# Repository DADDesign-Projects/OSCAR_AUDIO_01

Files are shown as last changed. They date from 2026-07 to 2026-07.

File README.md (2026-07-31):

# OSCAR Audio Board - OSCAR_AUDIO_01






## 📋 Description

Dedicated electronic board implementing the audio section of the OSCAR effects pedal (https://github.com/DADDesign-Projects/OSCAR_P01A01). This board handles all digital and analog audio processing required for the pedal's operation.

## 🚀 Evolutions

### V2
- Modification of the output summing stage to restore phase alignment identical to the input signal

### V2.1 (PCB V2.2)
- Addition of a second relay to enable true hardware bypass

## 🛠️ Technical Specifications

### Audio Codec
- **PCM3060**: 24-bit stereo audio codec
- **ADC**: 2-channel, 24-bit resolution
- **DAC**: 2-channel, 24-bit resolution
- **Sampling Rate**: Up to 96 kHz

### Analog Dry Channel
- **PGA2310/PGA2311**: Stereo volume controller
- **Analog dry path** for unaffected signal
- **Independent wet/dry mix control**

### Power Supply
- **Isolated Power**: Separate analog and digital domains
- **Input Voltage**: 12V DC
- **Low Noise Regulation**: Multiple LDO regulators
- **Consumption**: < 150mA

## 🛠️ Design Tools
This project was entirely designed using **KiCad 10.0**, the open-source electronics design.

## 📜 License
This project is licensed under the **Apache License 2.0**.

# 📬 Contact
Feel free to contact me for any questions, feedback, improvement suggestions, or collaboration proposals related to the FORGE framework or the OSCAR hardware platform.
I am always open to discussion and community contributions (daddesign.projects@gmail.com).

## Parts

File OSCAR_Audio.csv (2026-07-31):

Reference | Value | Footprint | Datasheet | Qty | DNP | Exclude from BOM | Exclude from Board
C1,C10 | 330p NPO | Capacitor_SMD:C_0805_2012Metric_Pad1.18x1.45mm_HandSolder |  | 2
C2,C9 | 220n | Capacitor_SMD:C_1206_3216Metric_Pad1.33x1.80mm_HandSolder |  | 2
C3,C8,C15,C19 | 10u X7R | Capacitor_SMD:C_1206_3216Metric_Pad1.33x1.80mm_HandSolder |  | 4
C4,C5,C11,C12 | 100p | Capacitor_SMD:C_1206_3216Metric_Pad1.33x1.80mm_HandSolder |  | 4
C6,C21,C22,C23,C24,C25,C26,C33,C35,C40,C42,C43,C45 | 100n | Capacitor_SMD:C_0805_2012Metric_Pad1.18x1.45mm_HandSolder |  | 13
C7,C41,C44 | 10u tal | Capacitor_Tantalum_SMD:CP_EIA-3528-21_Kemet-B_HandSolder |  | 3
C13,C16,C17,C20 | 470p NPO | Capacitor_SMD:C_0805_2012Metric_Pad1.18x1.45mm_HandSolder |  | 4
C14,C18 | 1.5n | Capacitor_SMD:C_0805_2012Metric_Pad1.18x1.45mm_HandSolder |  | 2
C27,C30,C38 | 100u | @Projet:CP_Elec_6.3x9.9_WM |  | 3
C28,C31,C37 | 20u | @Projet:CP_Elec_5x5.4_WM |  | 3
C29,C32,C34,C36 | 10u Tal | Capacitor_Tantalum_SMD:CP_EIA-3528-21_Kemet-B_HandSolder |  | 4
D1,D2 | 1N4148W | Diode_SMD:D_SOD-123 | https://www.vishay.com/docs/85748/1n4148w.pdf | 2
FB1,FB3 | FerriteBead | Inductor_SMD:L_1206_3216Metric_Pad1.22x1.90mm_HandSolder |  | 2
FB2,FB4 | FerriteBead_Small | Inductor_SMD:L_0805_2012Metric_Pad1.05x1.20mm_HandSolder |  | 2
J1 | InL | @Projet:Jack 6.25 | https://www.neutrik.com/en/product/nmj6hcd3 | 1
J2 | InR | @Projet:Jack 6.25 | https://www.neutrik.com/en/product/nmj6hcd3 | 1
J3 | OutR | @Projet:Jack 6.25 | https://www.neutrik.com/en/product/nmj6hcd3 | 1
J4 | OutL | @Projet:Jack 6.25 | https://www.neutrik.com/en/product/nmj6hcd3 | 1
J5 | SAI | Connector_PinHeader_2.54mm:PinHeader_1x07_P2.54mm_Vertical |  | 1
J6 | Vol | Connector_PinHeader_2.54mm:PinHeader_1x06_P2.54mm_Vertical |  | 1
J7,J8 | +12V | Connector_PinHeader_2.54mm:PinHeader_1x02_P2.54mm_Vertical |  | 2
J9 | ByPass | Connector_PinHeader_2.54mm:PinHeader_1x02_P2.54mm_Vertical |  | 1
K1,K2 | G6K-2F-Y | Relay_SMD:Relay_DPDT_Omron_G6K-2F-Y | http://omronfs.omron.com/en_US/ecb/products/pdf/en-g6k.pdf | 2
PS1 | A1209S 2W | @Projet:Converter_DCDC_TRACO_TBA2-xxxx_Dual_THT |  | 1
PS2 | B1209S | @Projet:Converter_DCDC_TRACO_TBA2-xxxx_Single_THT |  | 1
R1,R2,R10,R11,R17,R21,R28,R32,R40,R41,R42,R43,R44 | 10k | Resistor_SMD:R_1206_3216Metric_Pad1.30x1.75mm_HandSolder |  | 13
R3,R9 | 20k | Resistor_SMD:R_1206_3216Metric_Pad1.30x1.75mm_HandSolder |  | 2
R4,R6,R7,R8,R13,R14,R36,R51 | 1k | Resistor_SMD:R_1206_3216Metric_Pad1.30x1.75mm_HandSolder |  | 8
R5,R12,R37 | 220k | Resistor_SMD:R_1206_3216Metric_Pad1.30x1.75mm_HandSolder |  | 3
R15,R23,R26,R35 | 7.5k | Resistor_SMD:R_1206_3216Metric_Pad1.30x1.75mm_HandSolder |  | 4
R16,R20,R27,R31 | 820 | Resistor_SMD:R_1206_3216Metric_Pad1.30x1.75mm_HandSolder |  | 4
R18,R29 | 100 | Resistor_SMD:R_1206_3216Metric_Pad1.30x1.75mm_HandSolder |  | 2
R19,R22,R30,R33 | 22k | Resistor_SMD:R_1206_3216Metric_Pad1.30x1.75mm_HandSolder |  | 4
R24,R34 | 100k | Resistor_SMD:R_1206_3216Metric_Pad1.30x1.75mm_HandSolder |  | 2
R25,R52 | 1K | Resistor_SMD:R_1206_3216Metric_Pad1.30x1.75mm_HandSolder |  | 2
R38,R39 | 4.7k | Resistor_SMD:R_1206_3216Metric_Pad1.30x1.75mm_HandSolder |  | 2
R45,R48 | 120 0.1% | Resistor_SMD:R_0805_2012Metric_Pad1.20x1.40mm_HandSolder |  | 2
R46,R47 | 360 0.1% | Resistor_SMD:R_0805_2012Metric_Pad1.20x1.40mm_HandSolder |  | 2
R49 | 1M | Resistor_SMD:R_1206_3216Metric_Pad1.30x1.75mm_HandSolder |  | 1
R50 | 0 | Resistor_SMD:R_1206_3216Metric_Pad1.30x1.75mm_HandSolder |  | 1
RV1,RV2 | 10k | @Projet:Potentioneter Double 1 ligne |  | 2
TP1 | GNDA | TestPoint:TestPoint_Pad_4.0x4.0mm |  | 1
TP2 | GNDA | Connector_Pin:Pin_D1.3mm_L11.0mm |  | 1
U1 | OPA1642 | Package_SO:SOP-8_3.76x4.96mm_P1.27mm | https://www.ti.com/product/OPA1612 | 1
U2 | OPA1644 | Package_SO:SOIC-14_3.9x8.7mm_P1.27mm | https://www.ti.com/product/OPA1644 | 1
U3 | PCM3060 | Package_SO:TSSOP-28_4.4x9.7mm_P0.65mm | https://www.ti.com/lit/gpn/pcm3060 | 1
U4 | NE5532 | Package_SO:SOP-8_3.76x4.96mm_P1.27mm | http://www.ti.com/lit/ds/symlink/ne5532.pdf | 1
U5 | PGA2310 | Package_SO:SOIC-16W_7.5x10.3mm_P1.27mm | https://www.ti.com/product/PGA2310 | 1
U6 | LM317_SOT-223 | Package_TO_SOT_SMD:SOT-223-3_TabPin2 | http://www.ti.com/lit/ds/symlink/lm317.pdf | 1
U7 | LM337_SOT223 | Package_TO_SOT_SMD:SOT-223-3_TabPin2 | http://www.ti.com/lit/ds/symlink/lm337-n.pdf | 1
U8 | L78L05_SOT89 | Package_TO_SOT_SMD:SOT-89-3 | http://www.st.com/content/ccc/resource/technical/document/datasheet/15/55/e5/aa/23/5b/43/fd/CD00000446.pdf/files/CD00000446.pdf/jcr:content/translations/en.CD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 | 1

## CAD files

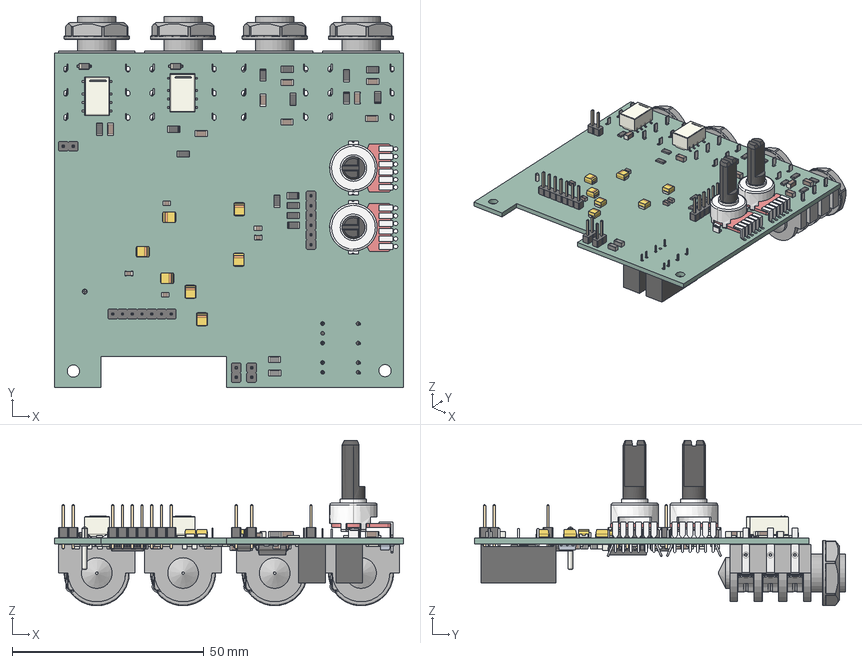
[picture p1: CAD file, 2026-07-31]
OSCAR_AUDIO_01.step
91.0 x 96.6 x 43.1 mm
R_1206_3216Metric x 48
CP_EIA-3528-21_Kemet-B x 7
PinHeader_1x07_P2.54mm_Vertical
C_0805_2012Metric x 21
PinHeader_1x06_P2.54mm_Vertical
C_1206_3216Metric x 10
L_1206_3216Metric x 2
Relay_DPDT_Omron_G6K-2F-Y x 2
PinHeader_1x02_P2.54mm_Vertical x 3
D_SOD-123 x 2
Nut x 4
Pin_1 x 12
Pin_2 x 12
SOIC-14_3.9x8.7mm_P1.27mm
R_0805_2012Metric x 4
SOT-223 x 2
OSCAR_AUDIO_01 1.75.1
B0512S-2W x 2
TSSOP-28_4.4x9.7mm_P0.65mm
SOIC-16W_7.5x10.3mm_P1.27mm
L_0805_2012Metric x 2
Pin_D1.3mm_L11.0mm
OSCAR_Audio_PCB

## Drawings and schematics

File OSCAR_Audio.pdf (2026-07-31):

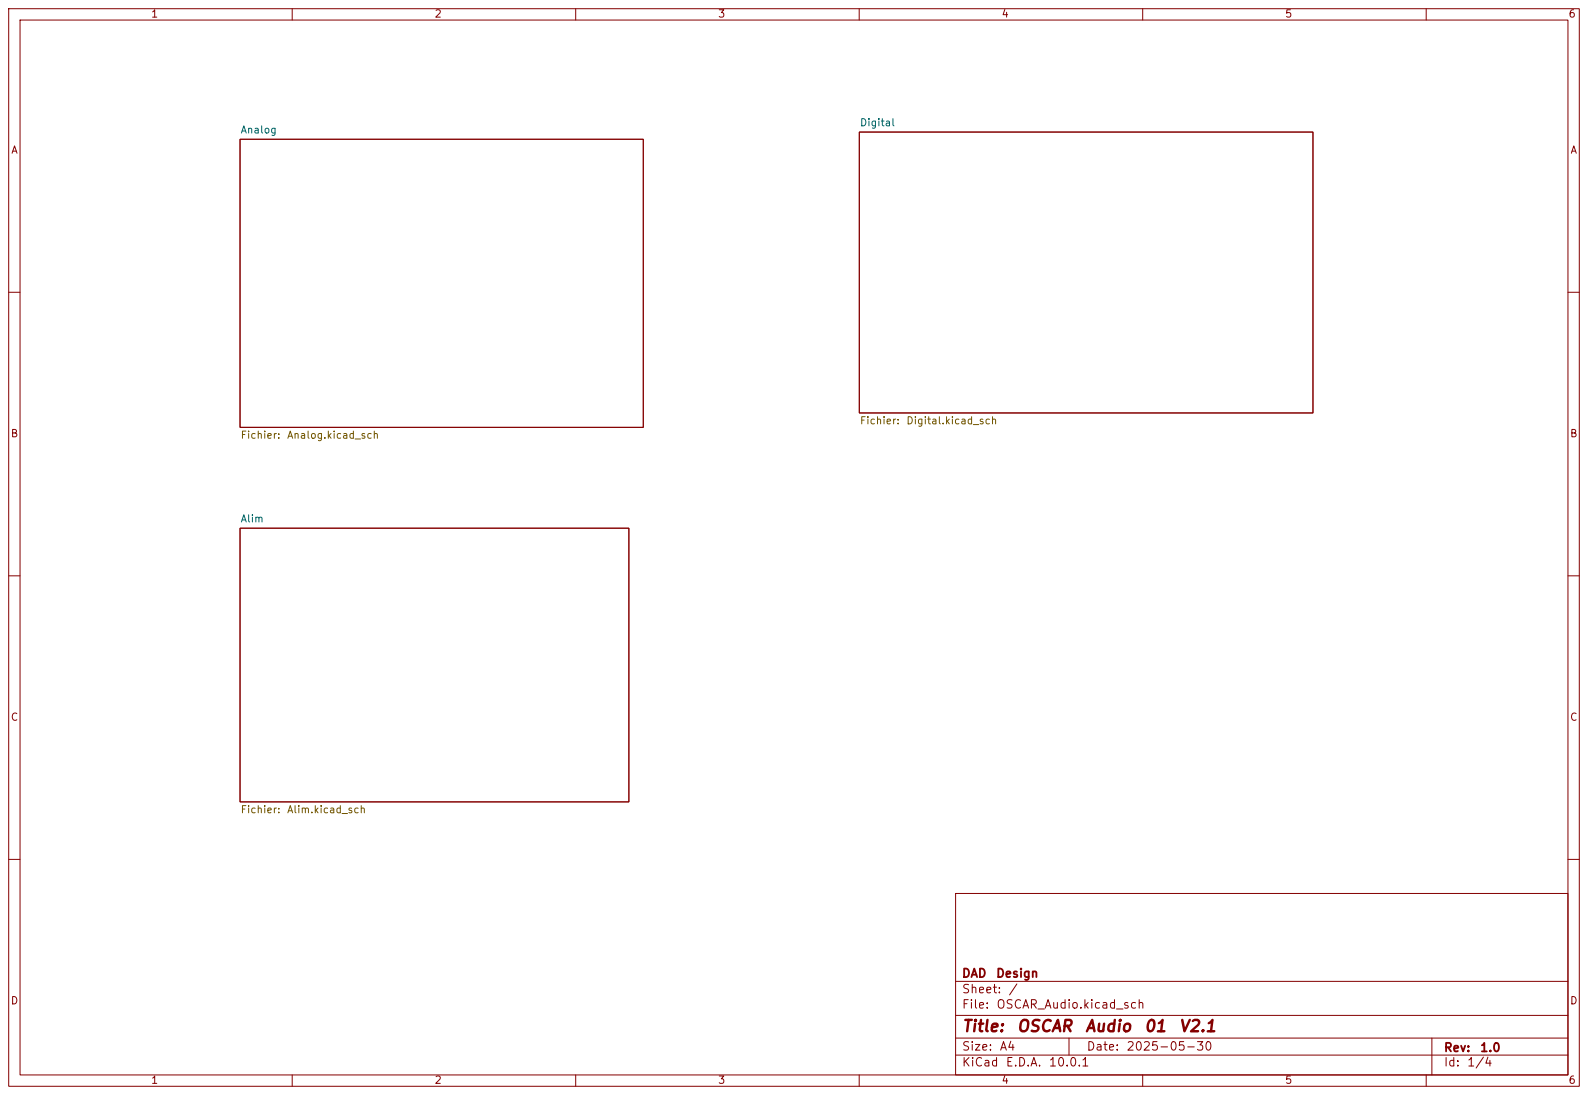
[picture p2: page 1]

Size: A4 | Rev: 1.0
KiCad E.D.A. 10.0.1 | Id: 1/4

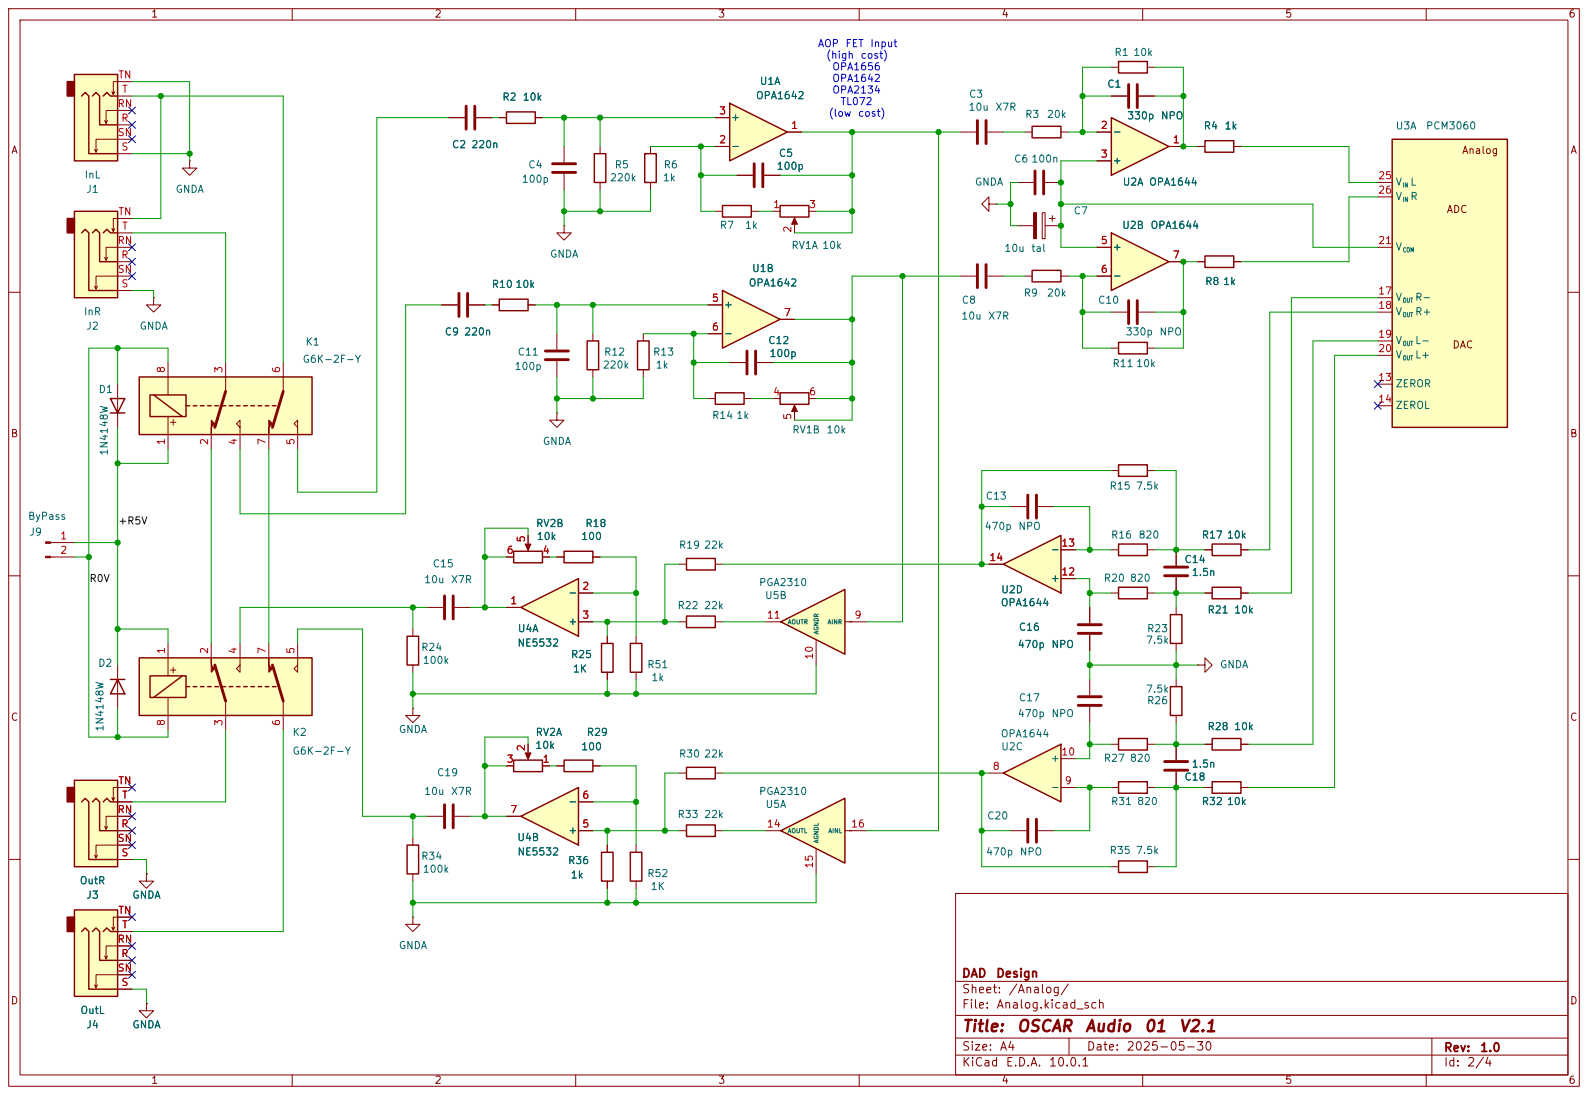
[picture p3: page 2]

AOP FET Input
Analog ZEROR 13
ZEROL 14 V OUT R- 17 V OUT R+ 18 V OUT L- 19 V OUT L+ 20 V COM 21 V IN L 25 V IN R

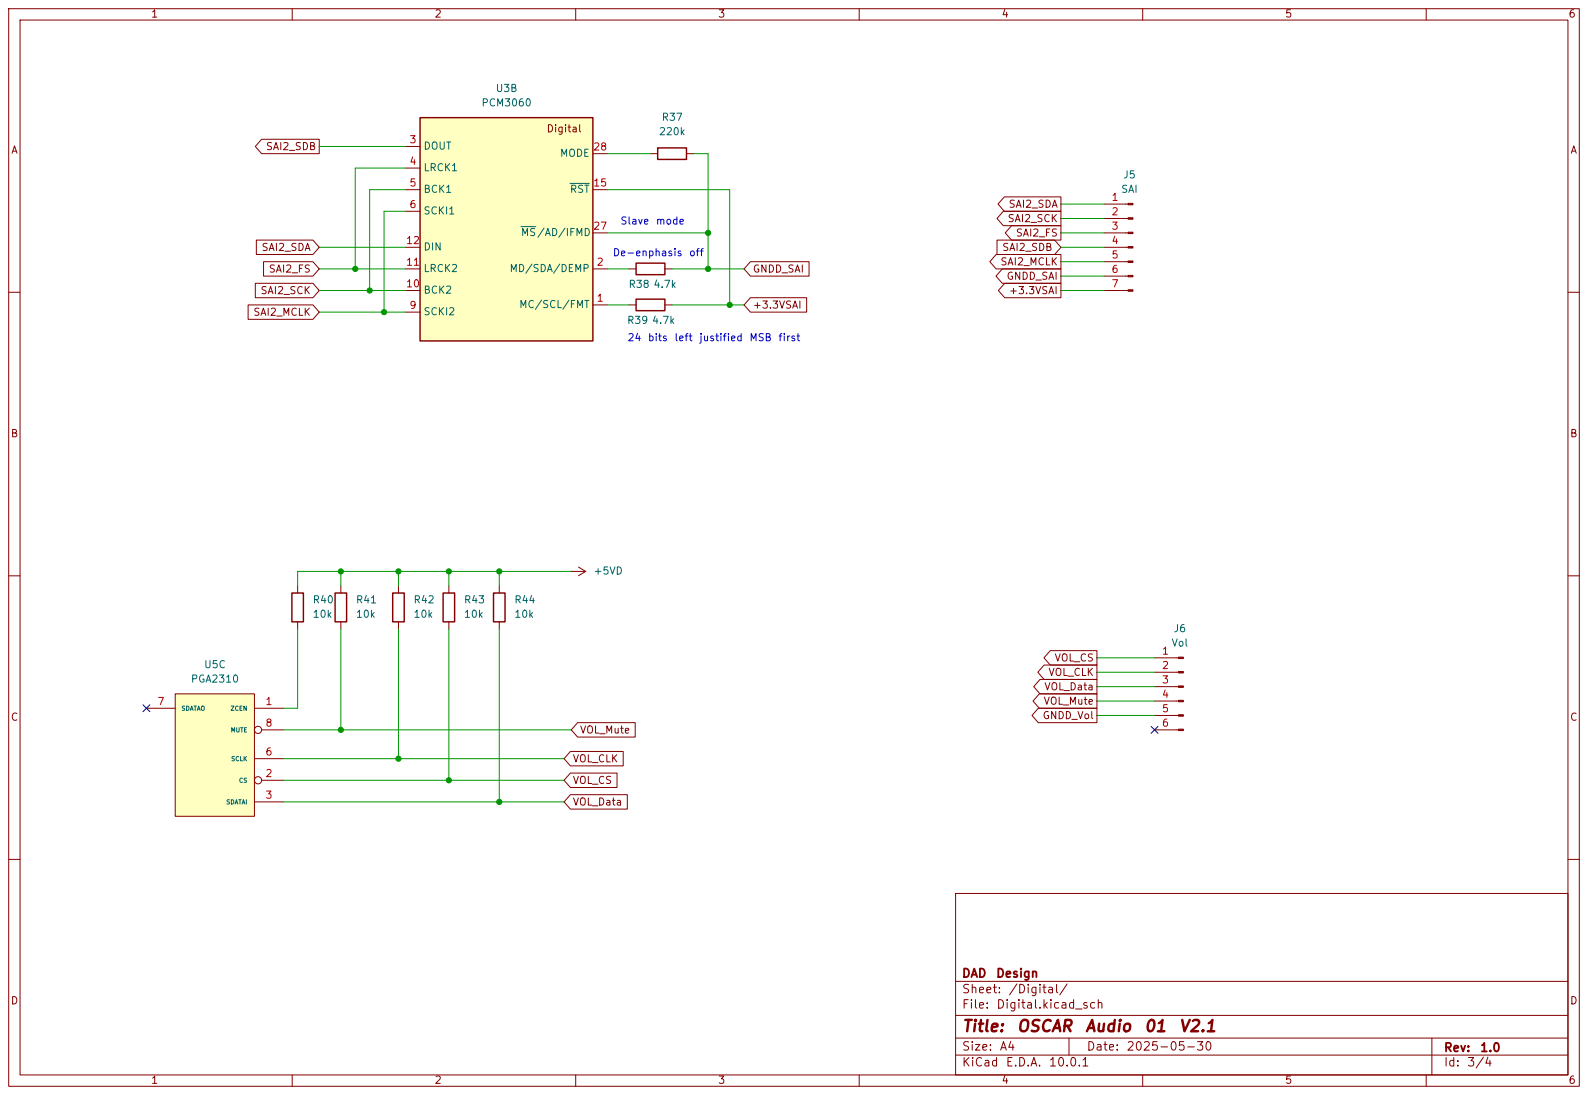
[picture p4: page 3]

GNDD_SAI +3.3VSAI 24 bits left justified MSB first De-enphasis off Slave mode

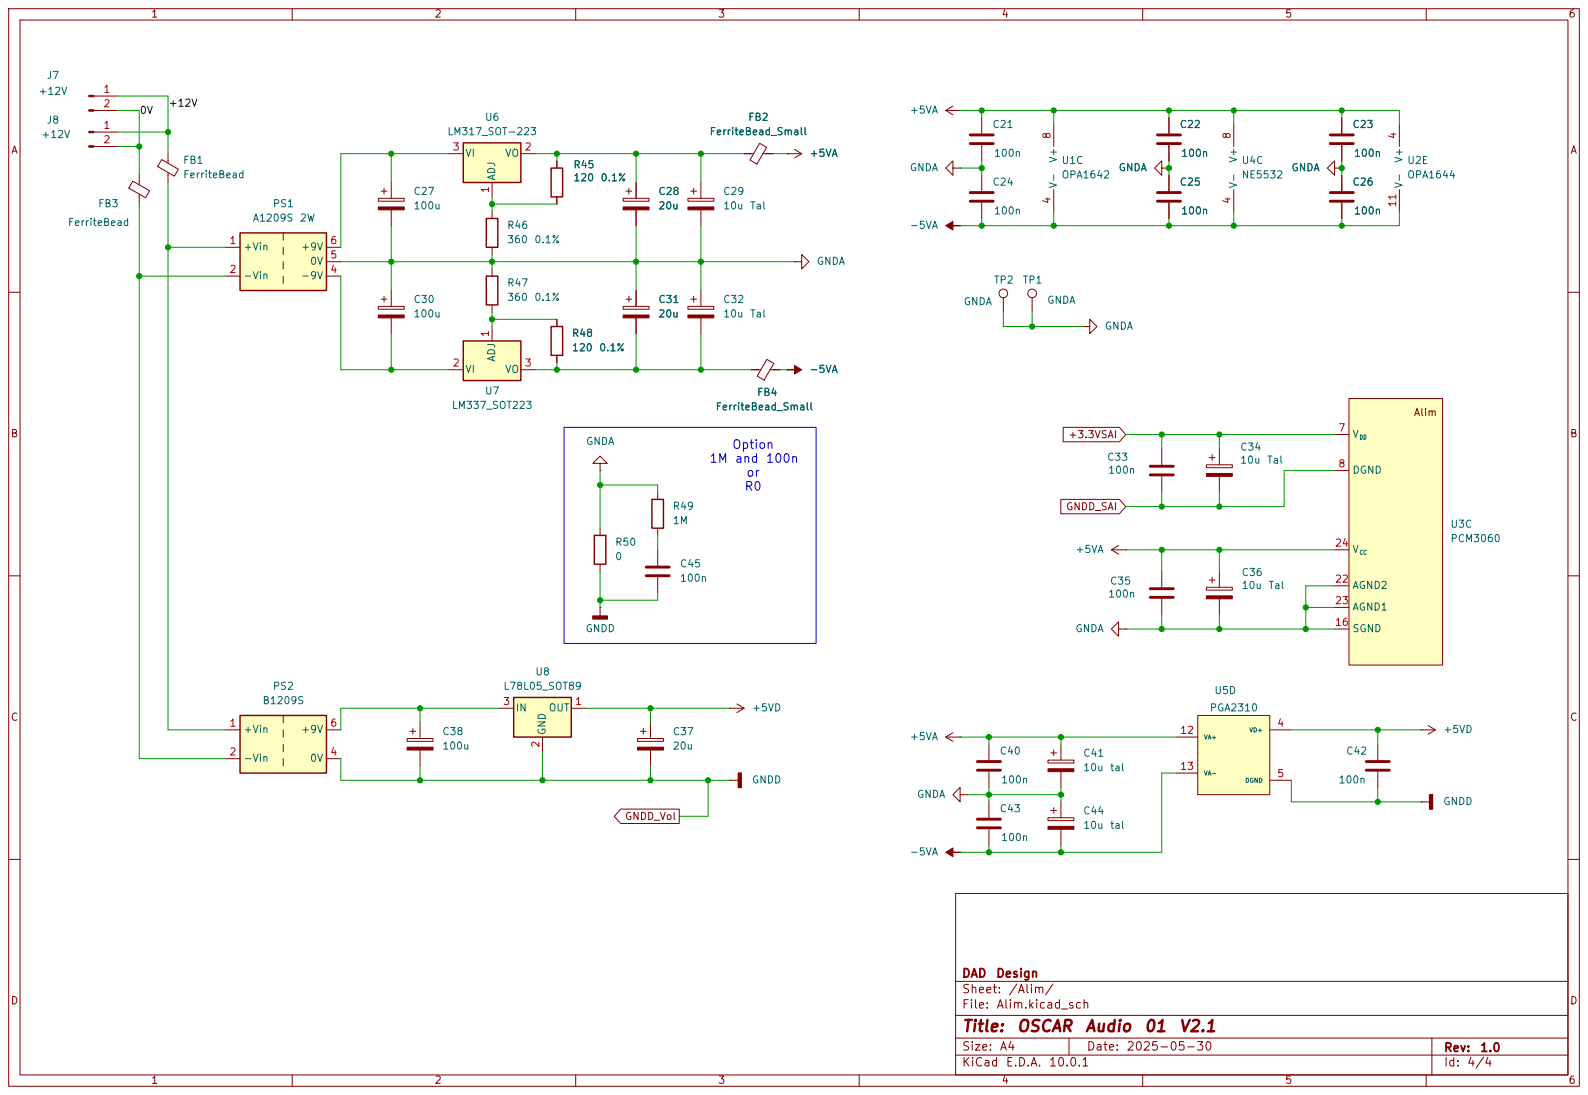
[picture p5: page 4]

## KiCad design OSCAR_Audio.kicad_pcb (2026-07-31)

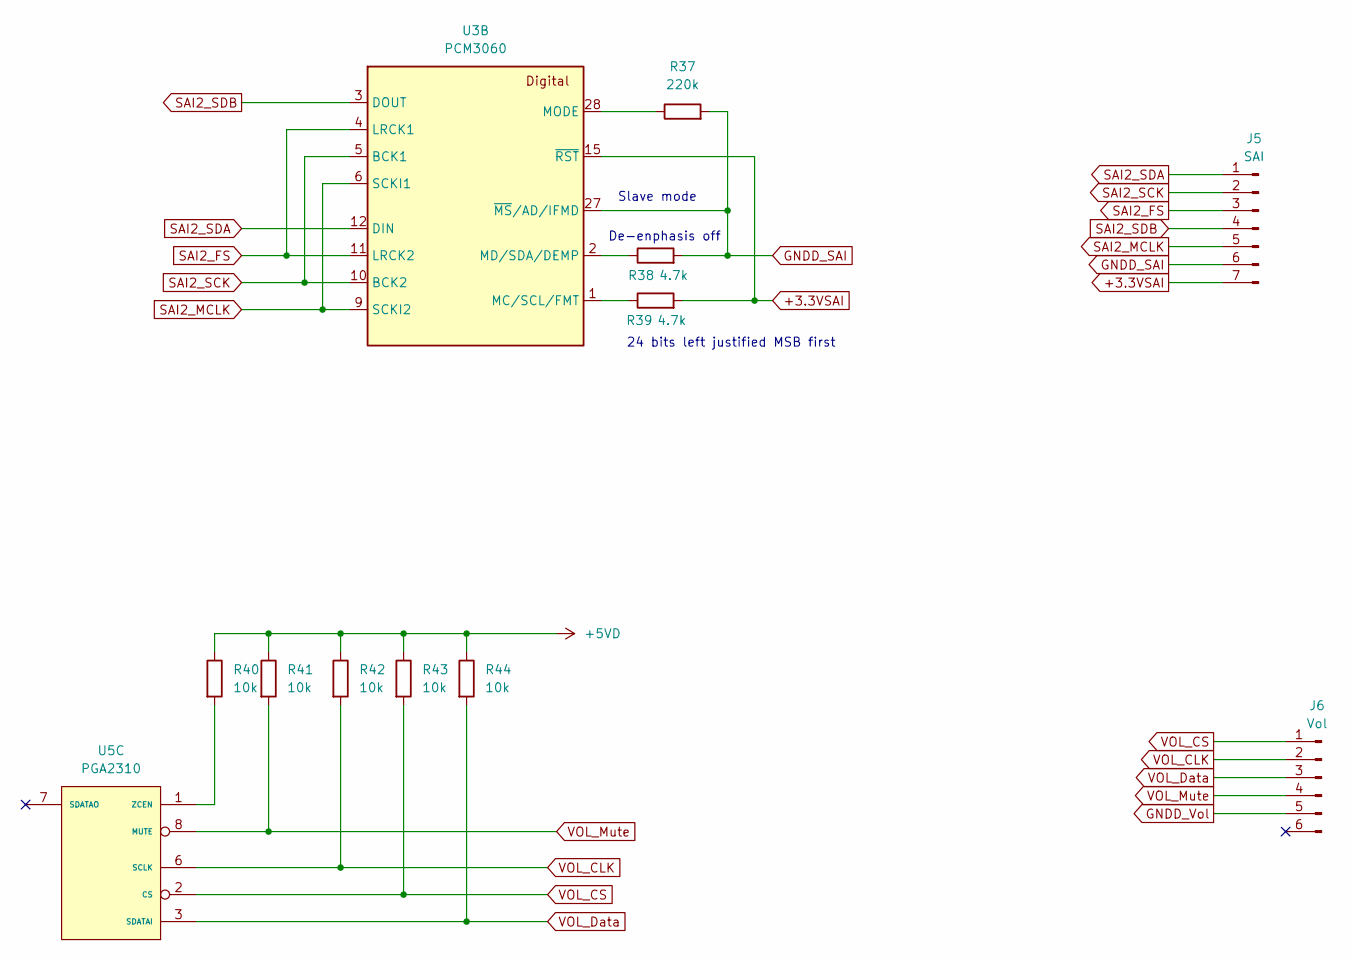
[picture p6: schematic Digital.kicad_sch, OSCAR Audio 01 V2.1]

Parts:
J5: SAI; PinHeader_1x07_P2.54mm_Vertical
J6: Vol; PinHeader_1x06_P2.54mm_Vertical
R37: 220k; R_1206_3216Metric_Pad1.30x1.75mm_HandSolder
R38, R39: 4.7k; R_1206_3216Metric_Pad1.30x1.75mm_HandSolder
R40, R41, R42, R43, R44: 10k; R_1206_3216Metric_Pad1.30x1.75mm_HandSolder
U3: PCM3060; TSSOP-28_4.4x9.7mm_P0.65mm
U5: PGA2310; SOIC-16W_7.5x10.3mm_P1.27mm

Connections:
+3.3VSAI: J5.7, R39.2, U3.15 (~RST); also elsewhere on the board
+5VD: R40.1, R41.1, R42.1, R43.1, R44.1; also elsewhere on the board
GNDD_SAI: J5.6, R37.2, R38.2, U3.27 (~MS/AD/IFMD); also elsewhere on the board
GNDD_Vol: J6.5; also elsewhere on the board
unnamed: R39.1, U3.1 (MC/SCL/FMT)
unnamed: R38.1, U3.2 (MD/SDA/DEMP)
unnamed: R37.1, U3.28 (MODE)
unnamed: R40.2, U5.1 (ZCEN)
SAI2_FS: J5.3, U3.4 (LRCK1), U3.11 (LRCK2)
SAI2_MCLK: J5.5, U3.6 (SCKI1), U3.9 (SCKI2)
SAI2_SCK: J5.2, U3.5 (BCK1), U3.10 (BCK2)
SAI2_SDA: J5.1, U3.12 (DIN)
SAI2_SDB: J5.4, U3.3 (DOUT)
VOL_CLK: J6.2, R42.2, U5.6 (SCLK)
VOL_CS: J6.1, R43.2, U5.2 (CS)
VOL_Data: J6.3, R44.2, U5.3 (SDATAI)
VOL_Mute: J6.4, R41.2, U5.8 (MUTE)

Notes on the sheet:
Slave mode
24 bits left justified MSB first
De-enphasis off

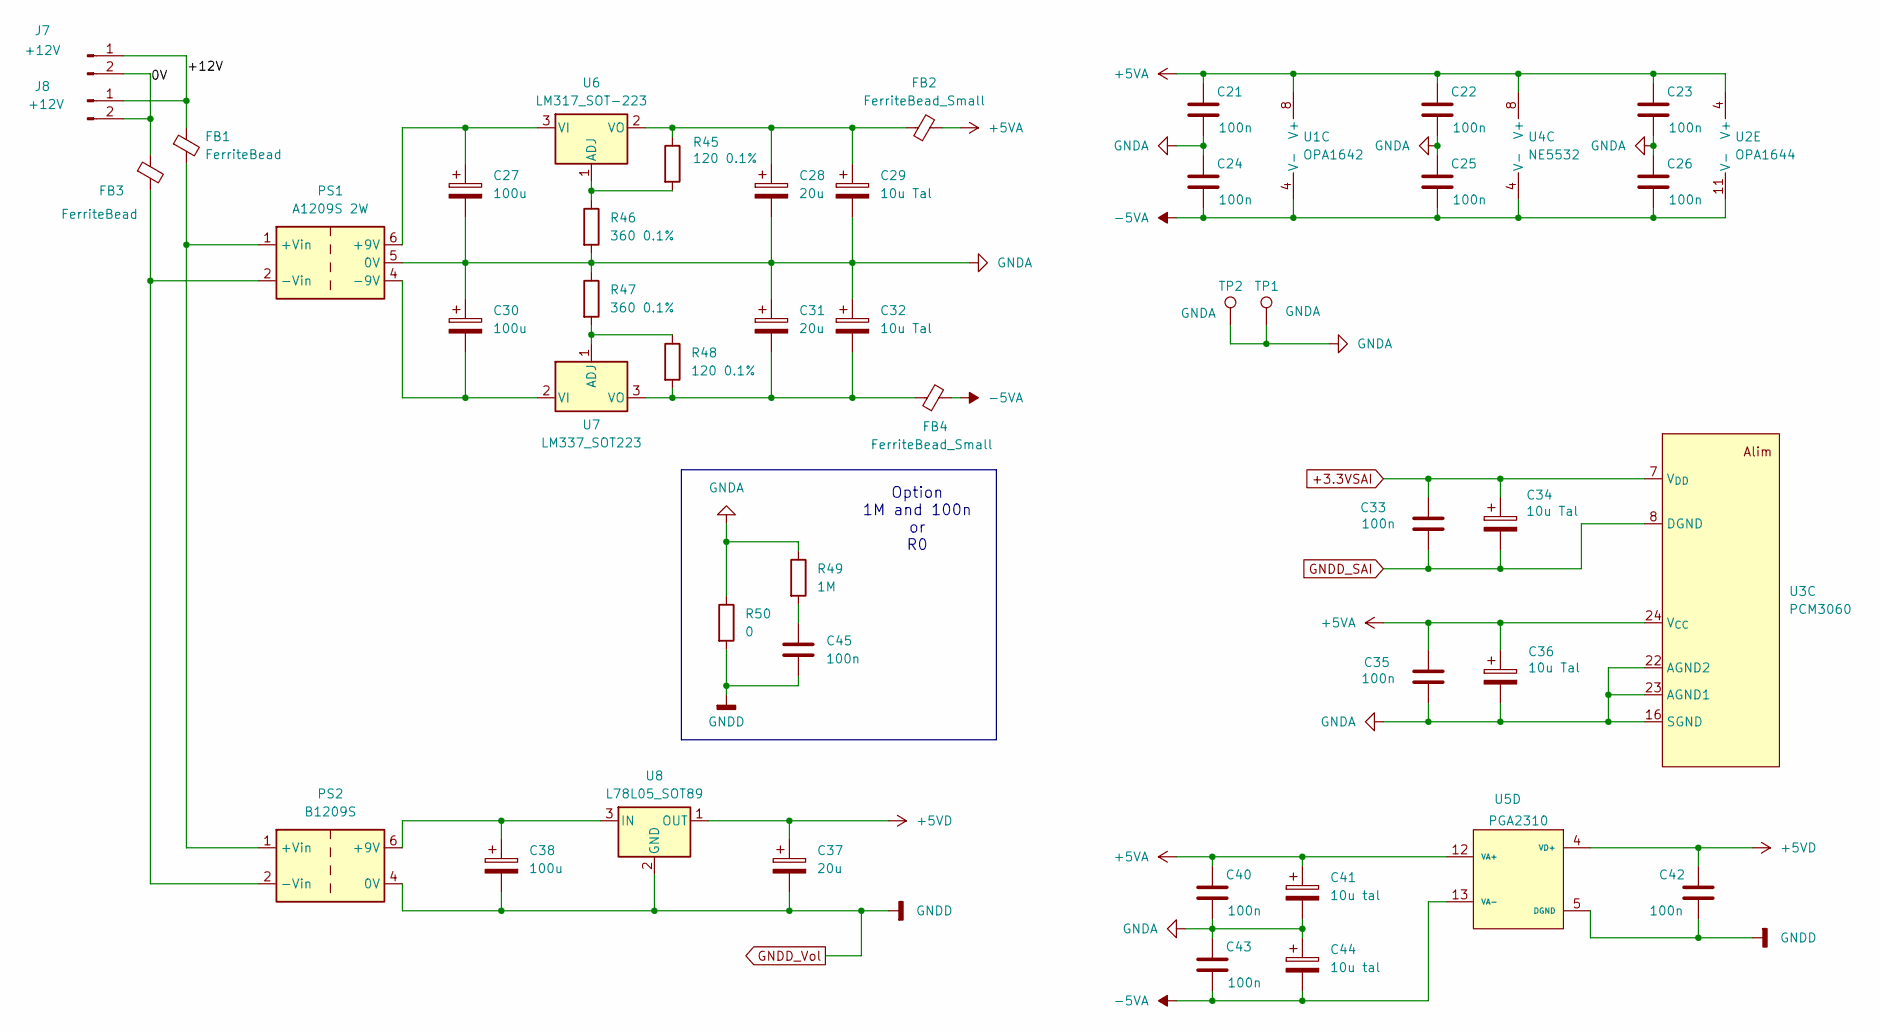
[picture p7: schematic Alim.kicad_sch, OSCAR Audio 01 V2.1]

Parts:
C21, C22, C23, C24, C25, C26, C33, C35, C40, C42, C43, C45: 100n; C_0805_2012Metric_Pad1.18x1.45mm_HandSolder
C27, C30, C38: 100u; CP_Elec_6.3x9.9_WM
C28, C31, C37: 20u; CP_Elec_5x5.4_WM
C29, C32, C34, C36: 10u Tal; CP_EIA-3528-21_Kemet-B_HandSolder
C41, C44: 10u tal; CP_EIA-3528-21_Kemet-B_HandSolder
FB1, FB3: FerriteBead; L_1206_3216Metric_Pad1.22x1.90mm_HandSolder
FB2, FB4: FerriteBead_Small; L_0805_2012Metric_Pad1.05x1.20mm_HandSolder
J7, J8: +12V; PinHeader_1x02_P2.54mm_Vertical
PS1: A1209S 2W; Converter_DCDC_TRACO_TBA2-xxxx_Dual_THT
PS2: B1209S; Converter_DCDC_TRACO_TBA2-xxxx_Single_THT
R45, R48: 120 0.1%; R_0805_2012Metric_Pad1.20x1.40mm_HandSolder
R46, R47: 360 0.1%; R_0805_2012Metric_Pad1.20x1.40mm_HandSolder
R49: 1M; R_1206_3216Metric_Pad1.30x1.75mm_HandSolder
R50: 0; R_1206_3216Metric_Pad1.30x1.75mm_HandSolder
TP1: GNDA; TestPoint_Pad_4.0x4.0mm
TP2: GNDA; Pin_D1.3mm_L11.0mm
U1: OPA1642; SOP-8_3.76x4.96mm_P1.27mm
U2: OPA1644; SOIC-14_3.9x8.7mm_P1.27mm
U3: PCM3060; TSSOP-28_4.4x9.7mm_P0.65mm
U4: NE5532; SOP-8_3.76x4.96mm_P1.27mm
U5: PGA2310; SOIC-16W_7.5x10.3mm_P1.27mm
U6: LM317_SOT-223; SOT-223-3_TabPin2
U7: LM337_SOT223; SOT-223-3_TabPin2
U8: L78L05_SOT89; SOT-89-3

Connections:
+3.3VSAI: C33.1, C34.1, U3.7 (V_{DD}); also elsewhere on the board
+5VA: C21.1, C22.1, C23.1, C35.1, C36.1, C40.1, C41.1, FB2.2, U1.8 (V+), U2.4 (V+), U3.24 (V_{CC}), U4.8 (V+), U5.12 (VA+)
+5VD: C37.1, C42.1, U5.4 (VD+), U8.1 (OUT); also elsewhere on the board
-5VA: C24.2, C25.2, C26.2, C43.2, C44.2, FB4.2, U1.4 (V-), U2.11 (V-), U4.4 (V-), U5.13 (VA-)
/Alim/0V: FB3.1, J7.2, J8.2
/Alim/+12V: FB1.1, J7.1, J8.1
GNDA: C21.2, C22.2, C23.2, C24.1, C25.1, C26.1, C27.2, C28.2, C29.2, C30.1, C31.1, C32.1, C35.2, C36.2, C40.2, C41.2, C43.1, C44.1, PS1.5 (0V), R46.2, R47.1, R49.1, R50.1, TP1.1 (1_1), TP2.1 (1_1), U3.16 (SGND), U3.22 (AGND2), U3.23 (AGND1); also elsewhere on the board
GNDD_SAI: C33.2, C34.2, U3.8 (DGND); also elsewhere on the board
GNDD_Vol: C37.2, C38.2, C42.2, C45.2, PS2.4 (0V), R50.2, U5.5 (DGND), U8.2 (GND); also elsewhere on the board
unnamed: C45.1, R49.2
unnamed: C27.1, PS1.6 (+9V), U6.3 (VI)
unnamed: FB1.2, PS1.1 (+Vin), PS2.1 (+Vin)
unnamed: C30.2, PS1.4 (-9V), U7.2 (VI)
unnamed: FB3.2, PS1.2 (-Vin), PS2.2 (-Vin)
unnamed: C38.1, PS2.6 (+9V), U8.3 (IN)
unnamed: R45.2, R46.1, U6.1 (ADJ)
unnamed: C28.1, C29.1, FB2.1, R45.1, U6.2 (VO)
unnamed: R47.2, R48.1, U7.1 (ADJ)
unnamed: C31.2, C32.2, FB4.1, R48.2, U7.3 (VO)

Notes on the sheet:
Option 1M and 100n or R0

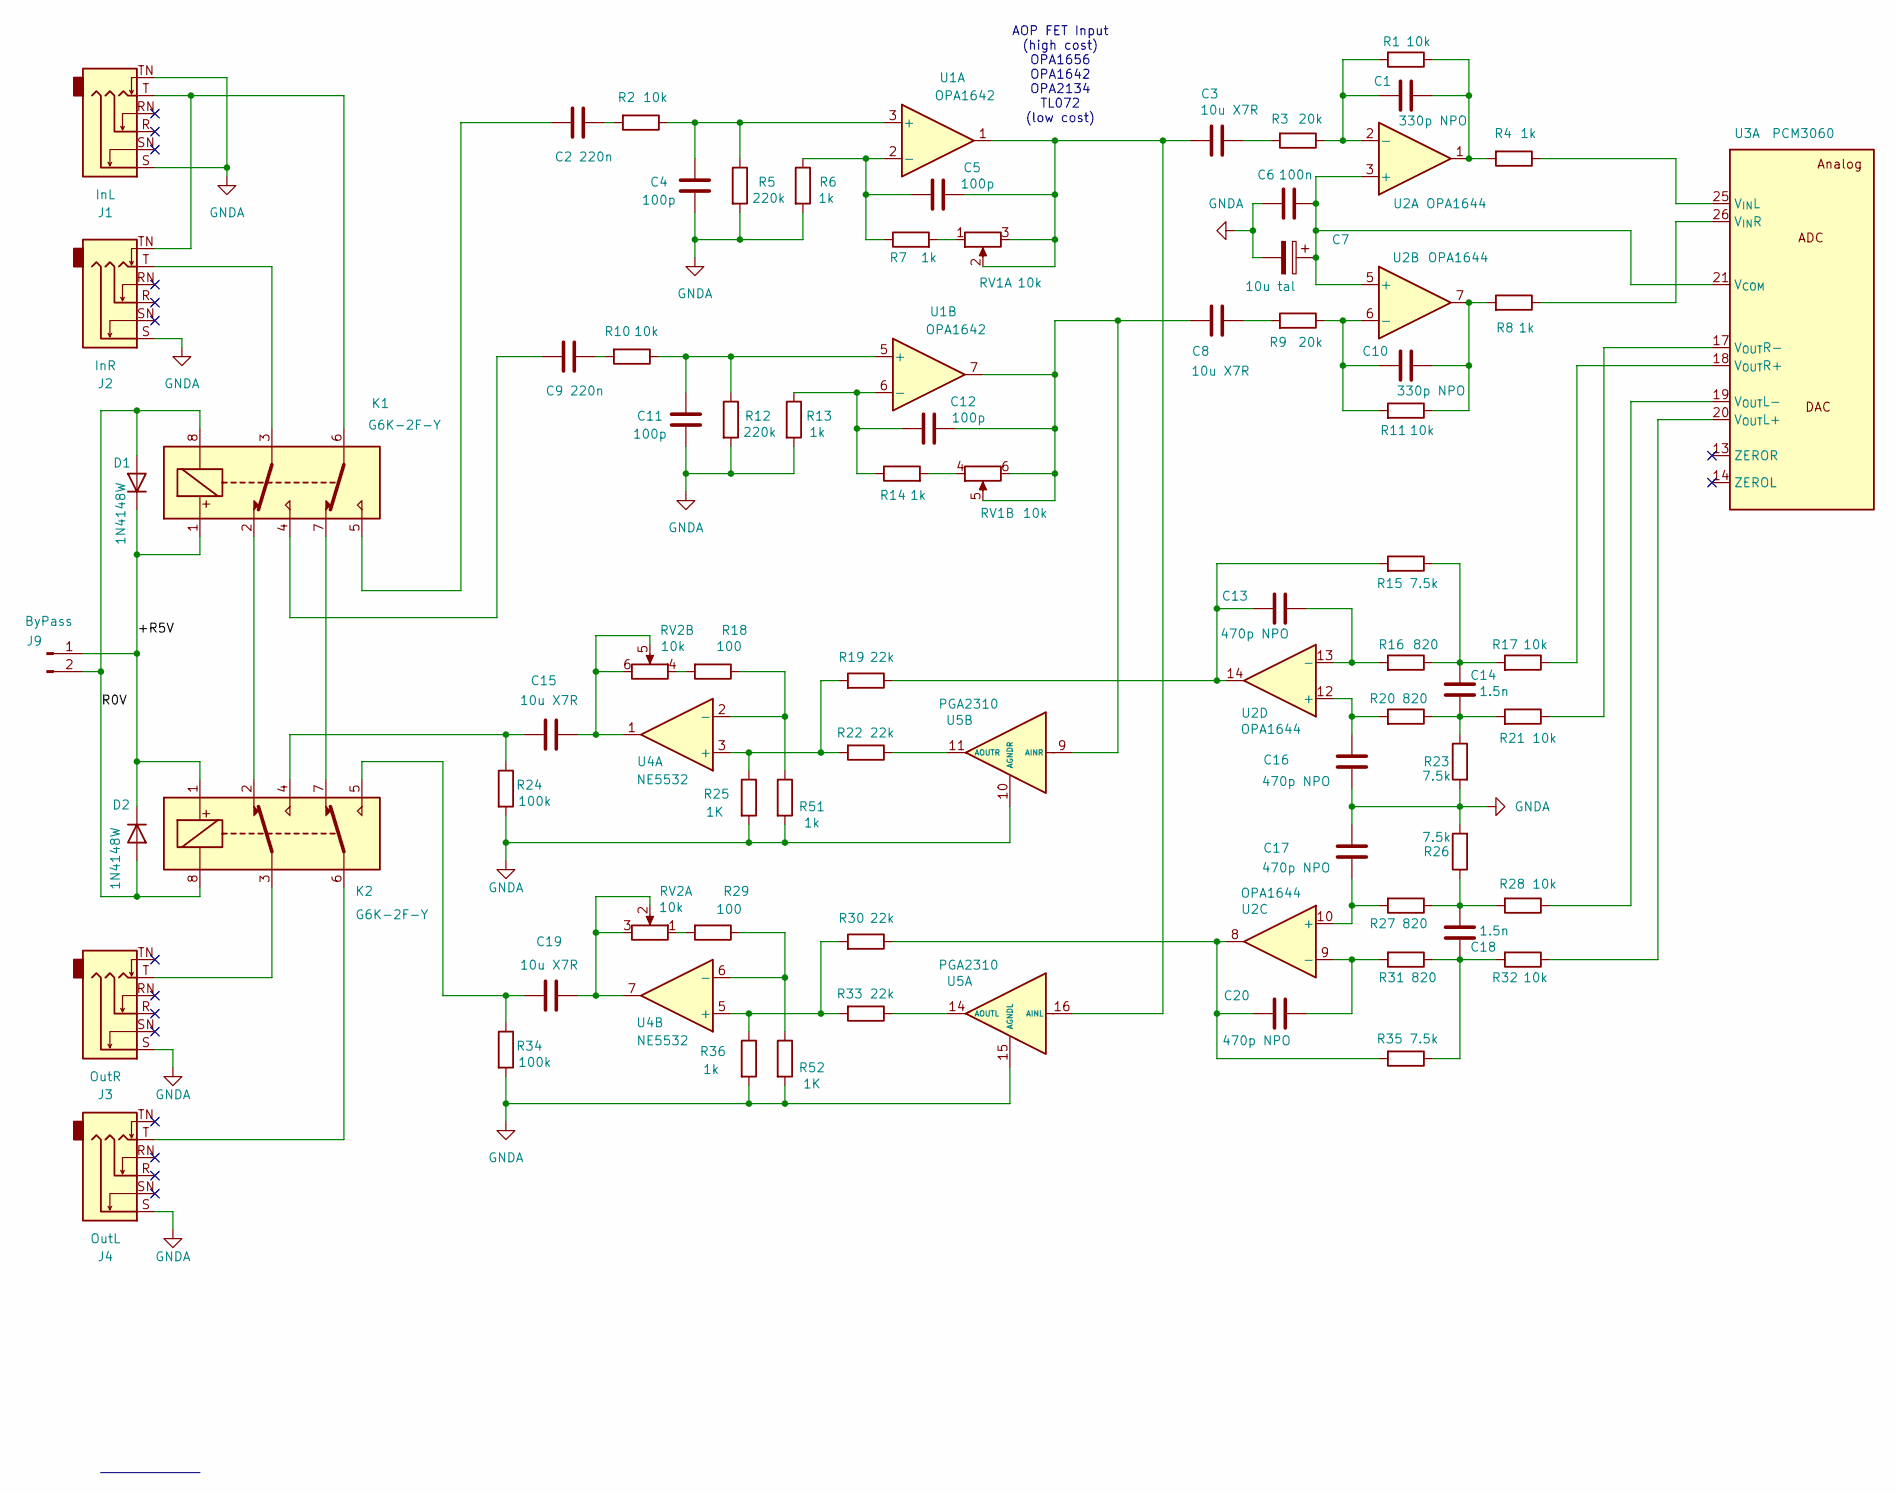
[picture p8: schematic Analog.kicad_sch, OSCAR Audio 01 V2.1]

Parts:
C1, C10: 330p NPO; C_0805_2012Metric_Pad1.18x1.45mm_HandSolder
C2, C9: 220n; C_1206_3216Metric_Pad1.33x1.80mm_HandSolder
C3, C8, C15, C19: 10u X7R; C_1206_3216Metric_Pad1.33x1.80mm_HandSolder
C4, C5, C11, C12: 100p; C_1206_3216Metric_Pad1.33x1.80mm_HandSolder
C6: 100n; C_0805_2012Metric_Pad1.18x1.45mm_HandSolder
C7: 10u tal; CP_EIA-3528-21_Kemet-B_HandSolder
C13, C16, C17, C20: 470p NPO; C_0805_2012Metric_Pad1.18x1.45mm_HandSolder
C14, C18: 1.5n; C_0805_2012Metric_Pad1.18x1.45mm_HandSolder
D1, D2: 1N4148W; D_SOD-123
J1: InL; Jack 6.25
J2: InR; Jack 6.25
J3: OutR; Jack 6.25
J4: OutL; Jack 6.25
J9: ByPass; PinHeader_1x02_P2.54mm_Vertical
K1, K2: G6K-2F-Y; Relay_DPDT_Omron_G6K-2F-Y
R1, R2, R10, R11, R17, R21, R28, R32: 10k; R_1206_3216Metric_Pad1.30x1.75mm_HandSolder
R3, R9: 20k; R_1206_3216Metric_Pad1.30x1.75mm_HandSolder
R4, R6, R7, R8, R13, R14, R36, R51: 1k; R_1206_3216Metric_Pad1.30x1.75mm_HandSolder
R5, R12: 220k; R_1206_3216Metric_Pad1.30x1.75mm_HandSolder
R15, R23, R26, R35: 7.5k; R_1206_3216Metric_Pad1.30x1.75mm_HandSolder
R16, R20, R27, R31: 820; R_1206_3216Metric_Pad1.30x1.75mm_HandSolder
R18, R29: 100; R_1206_3216Metric_Pad1.30x1.75mm_HandSolder
R19, R22, R30, R33: 22k; R_1206_3216Metric_Pad1.30x1.75mm_HandSolder
R24, R34: 100k; R_1206_3216Metric_Pad1.30x1.75mm_HandSolder
R25, R52: 1K; R_1206_3216Metric_Pad1.30x1.75mm_HandSolder
RV1, RV2: 10k; Potentioneter Double 1 ligne
U1: OPA1642; SOP-8_3.76x4.96mm_P1.27mm
U2: OPA1644; SOIC-14_3.9x8.7mm_P1.27mm
U3: PCM3060; TSSOP-28_4.4x9.7mm_P0.65mm
U4: NE5532; SOP-8_3.76x4.96mm_P1.27mm
U5: PGA2310; SOIC-16W_7.5x10.3mm_P1.27mm

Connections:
/Analog/+R5V: D1.1 (K), D2.1 (K), J9.1, K1.1, K2.1
/Analog/R0V: D1.2 (A), D2.2 (A), J9.2, K1.8, K2.8
GNDA: C4.1, C6.1, C7.2, C11.1, C16.1, C17.1, J1.S, J1.TN, J2.S, J3.S, J4.S, R5.2, R6.2, R12.2, R13.2, R23.2, R24.2, R25.2, R26.2, R34.2, R36.2, R51.2, R52.2, U5.10 (AGNDR), U5.15 (AGNDL); also elsewhere on the board
unnamed: C1.2, R1.1, R4.2, U2.1
unnamed: C2.1, K1.5
unnamed: C2.2, R2.2
unnamed: C3.2, R3.2
unnamed: C8.2, R9.2
unnamed: C9.1, K1.4
unnamed: C9.2, R10.2
unnamed: C10.2, R8.2, R11.1, U2.7
unnamed: C13.2, R15.2, R19.1, U2.14
unnamed: C14.1, R20.1, R21.2, R23.1
unnamed: C14.2, R15.1, R16.1, R17.2
unnamed: C15.1, K2.4, R24.1
unnamed: C15.2, RV2.5, RV2.6, U4.1
unnamed: C18.1, R26.1, R27.1, R28.2
unnamed: C18.2, R31.1, R32.2, R35.1
unnamed: C19.1, K2.5, R34.1
unnamed: C19.2, RV2.2, RV2.3, U4.7
unnamed: C20.2, R30.1, R35.2, U2.8
unnamed: J1.T, J2.TN, K1.6
unnamed: J2.T, K1.3
unnamed: J3.T, K2.3
unnamed: J4.T, K2.6
unnamed: K1.2, K2.2
unnamed: K1.7, K2.7
unnamed: R7.2, RV1.1
unnamed: R14.2, RV1.4
unnamed: R18.2, RV2.4
unnamed: R29.2, RV2.1
unnamed: C4.2, R2.1, R5.1, U1.3 (+)
unnamed: C5.1, R6.1, R7.1, U1.2 (-)
unnamed: C11.2, R10.1, R12.1, U1.5 (+)
unnamed: C12.1, R13.1, R14.1, U1.6 (-)
unnamed: C6.2, C7.1, U2.3 (+), U2.5 (+), U3.21 (V_{COM})
unnamed: C1.1, R1.2, R3.1, U2.2 (-)
unnamed: C10.1, R9.1, R11.2, U2.6 (-)
unnamed: C17.2, R27.2, U2.10 (+)
unnamed: C20.1, R31.2, U2.9 (-)
unnamed: C16.2, R20.2, U2.12 (+)
unnamed: C13.1, R16.2, U2.13 (-)
unnamed: R4.1, U3.25 (V_{IN}L)
unnamed: R8.1, U3.26 (V_{IN}R)
unnamed: R32.1, U3.20 (V_{OUT}L+)
unnamed: R28.1, U3.19 (V_{OUT}L-)
unnamed: R17.1, U3.18 (V_{OUT}R+)
unnamed: R21.1, U3.17 (V_{OUT}R-)
unnamed: R19.2, R22.2, R25.1, U4.3 (+)
unnamed: R18.1, R51.1, U4.2 (-)
unnamed: R30.2, R33.2, R36.1, U4.5 (+)
unnamed: R29.1, R52.1, U4.6 (-)
unnamed: C3.1, C5.2, RV1.2, RV1.3, U1.1, U5.16 (AINL)
unnamed: R33.1, U5.14 (AOUTL)
unnamed: C8.1, C12.2, RV1.5, RV1.6, U1.7, U5.9 (AINR)
unnamed: R22.1, U5.11 (AOUTR)

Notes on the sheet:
AOP FET Input (high cost) OPA1656 OPA1642 OPA2134 TL072 (low cost)

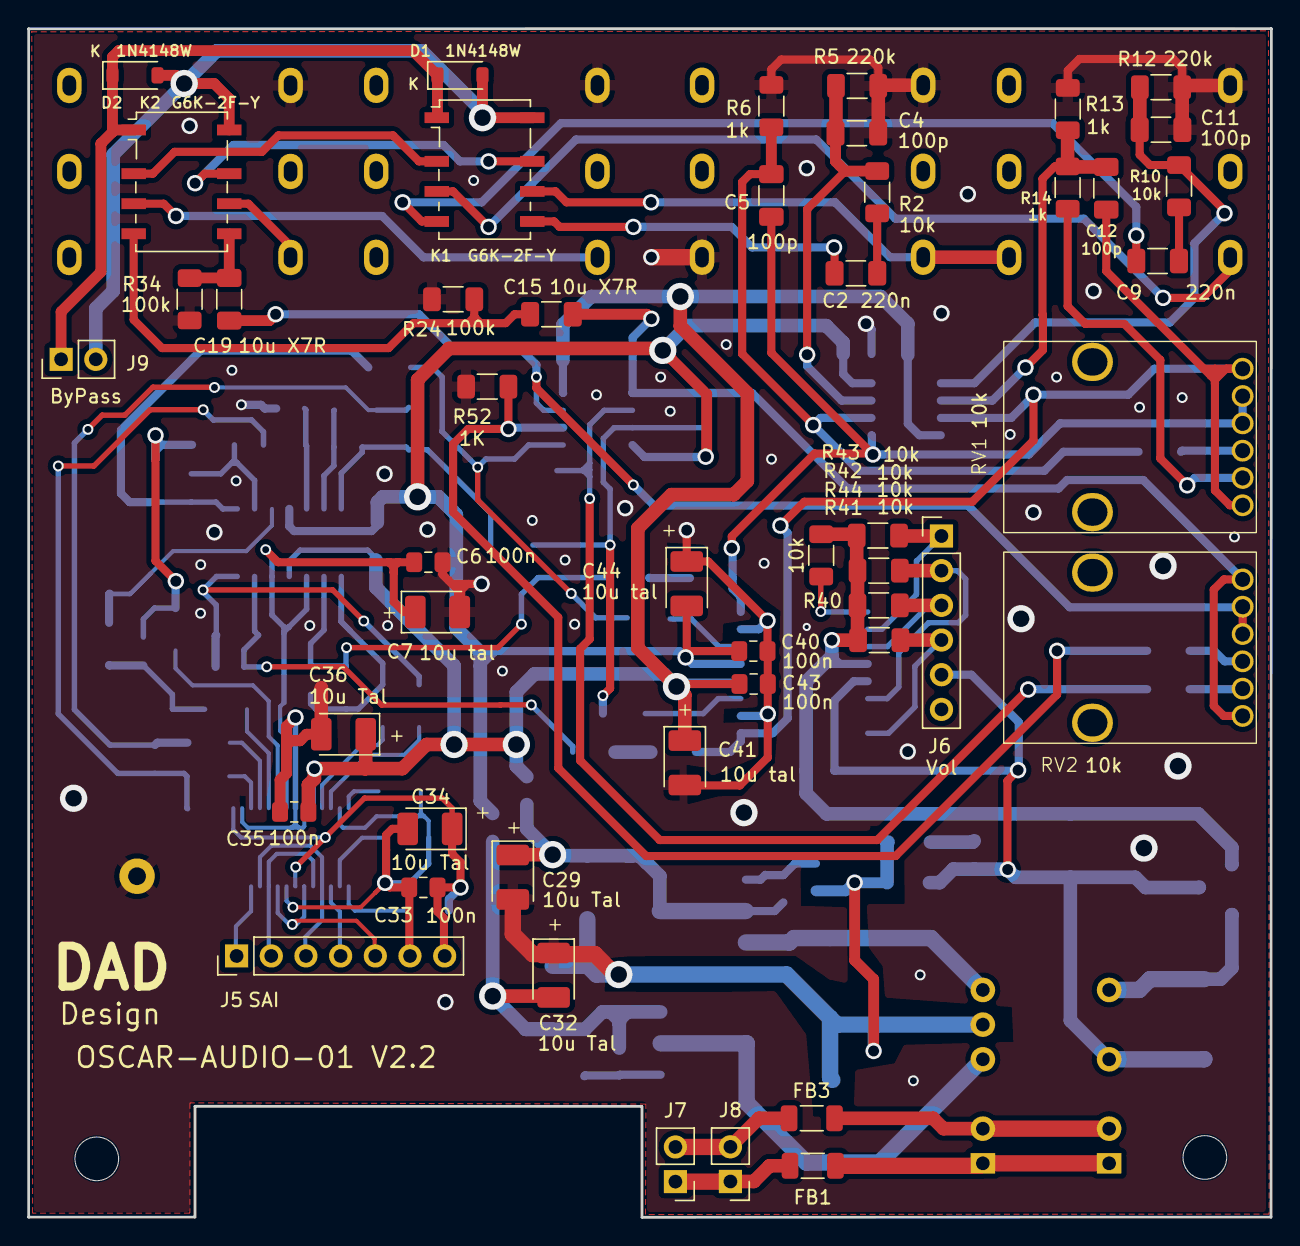
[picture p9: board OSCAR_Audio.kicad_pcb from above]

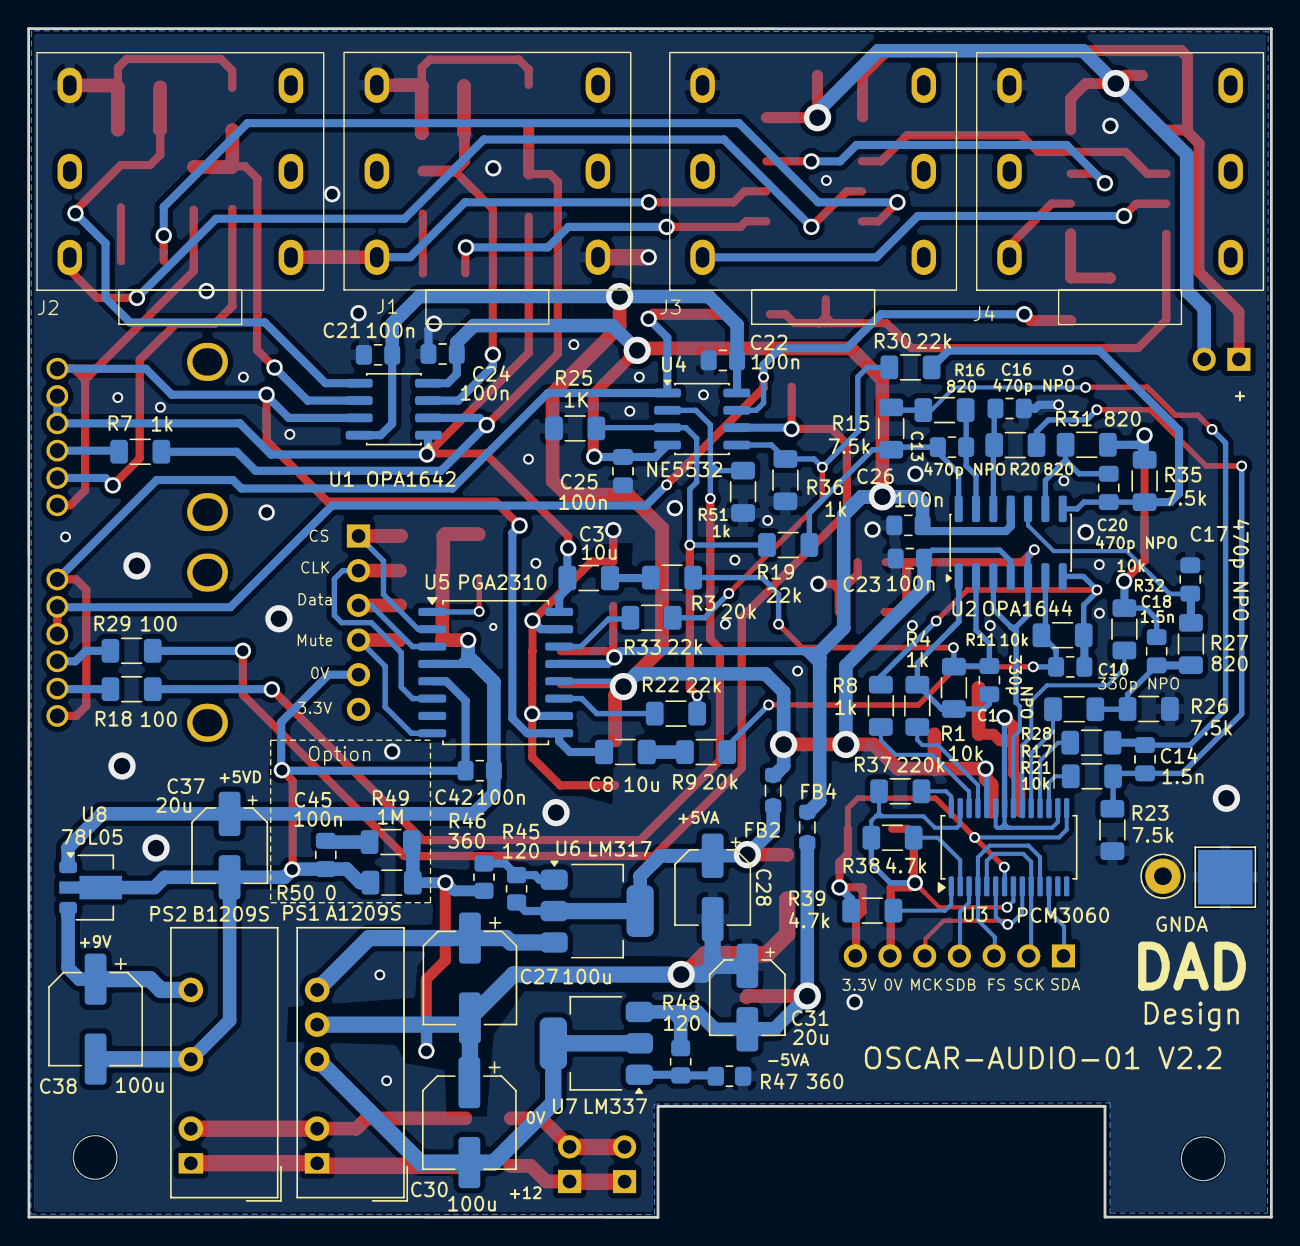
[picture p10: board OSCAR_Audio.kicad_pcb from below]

Board: 2 copper layers, 91.0 x 87.1 mm, 127 parts (79 on the bottom side), 87 nets.

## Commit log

2025-11-16 Update README with project details and specs
    Added detailed description and specifications for OSCAR Audio Board.
2025-11-16 Update README with KiCad badge and design tools info
    Added KiCad badge and design tools section to README.
2026-02-13 Fix typo OPA1612 -> OPA1642. Note: an OPA with FET inputs is necessary here.
    /!\ An OPA with FET inputs is necessary here.
    [Alim.kicad_sch, Analog.kicad_sch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]
2026-04-05 Invert output summing stage to maintain correct phase
    [Alim.kicad_sch, Analog.kicad_sch, Digital.kicad_sch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]
2026-04-06 Define R25 and R36 to 1k
    [Analog.kicad_sch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]
2026-07-31 Addition of a second relay to enable true hardware bypass
    [Alim.kicad_sch, Analog.kicad_sch, Digital.kicad_sch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]

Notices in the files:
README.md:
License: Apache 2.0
